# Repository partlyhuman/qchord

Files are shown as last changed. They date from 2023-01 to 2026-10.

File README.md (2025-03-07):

# Suzuki QChord Projects

Things that work with the Suzuki QChord, primarily a reproduction QCard that can be built with completely off-the-shelf parts. These projects are under active development.

# Physical devices

## [Q-Card Multicart QMC-001](pcbs/qcard-multicart)

You can get one as long as stock lasts <a href="https://ko-fi.com/s/ca15ec594a">at my Ko-Fi shop!</a>
<br>


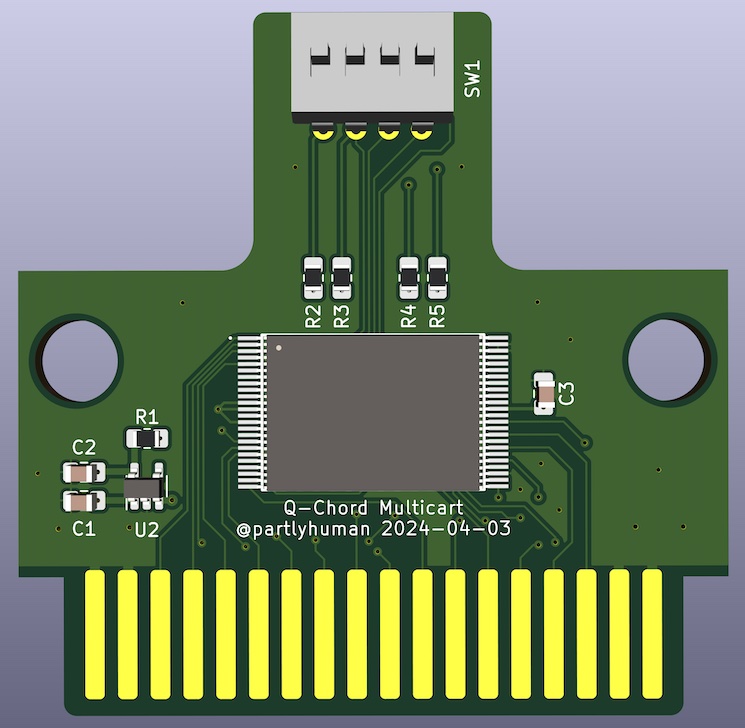
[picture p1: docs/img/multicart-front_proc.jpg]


A single cartridge that contains the entire Q-Card library, selectable by dip switches. The flash should be programmed prior to assembly, by concatenating the 4Mbit dumps you can find on archive.org.

## [Single Q-Card Reproduction](pcbs/qcard-single)

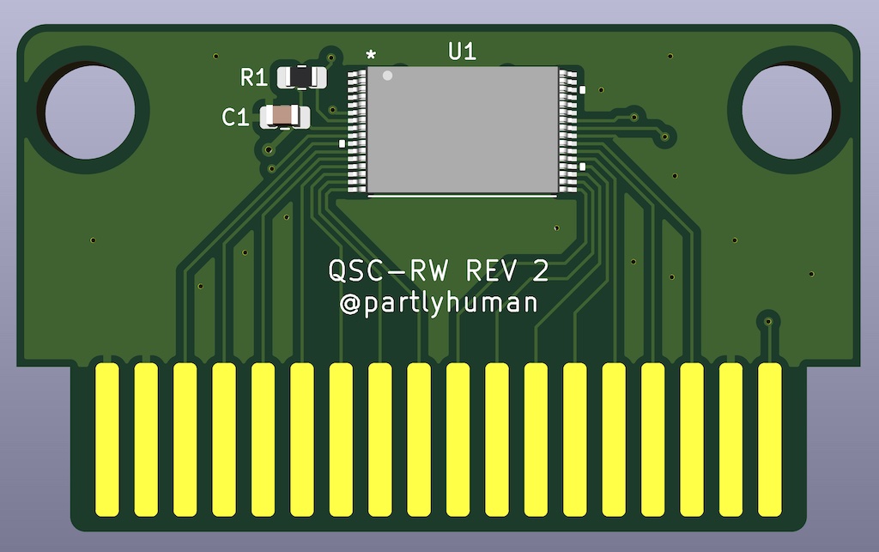
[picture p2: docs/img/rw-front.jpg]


A rewriteable reproduction QCard PCB using SMD components. The flash module uses a TSOP32 package. It can be reprogrammed after assembly with the programmer adapter below.

# [Documentation](docs/)

Including 

* my research notes on the Q-Card hardware & connector
* my reverse-engineered Q-Card format
* continuing research into the sound bank present on Q-Chord

# [Software](software/)

Primarily, the `qcard` command-line tool that can be used to convert MIDI to and from Q-Cards.

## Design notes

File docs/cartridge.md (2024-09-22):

# Hardware Notes

## Cartridge port

| description | bottom edge | top edge | description  |
| --- | --- | --- | --- |
| +5V | 1 | 2 | GND |
| A18 | 3 | 4 | GND |
| A17 | 5 | 6 | A16 |
| A14 | 7 | 8 | A15 |
| A13 | 9 | 10 | A12 |
| A8 | 11 | 12 | A7 |
| A9 | 13 | 14 | A6 |
| A11 | 15 | 16 | A5 |
| /OE | 17 | 18 | A4 |
| A10 | 19 | 20 | A3 |
| /CE | 21 | 22 | A2 |
| D7 | 23 | 24 | A1 |
| D6 | 25 | 26 | A0 |
| D5 | 27 | 28 | D0 |
| D4 | 29 | 30 | D1 |
| D3 | 31 | 32 | D2 |
| GND | 33 | 34 | GND/INSERTED |
| GND | 35 | 36 | NC |

### Notes
* QSC/QRD PCBs are labeled with pin 1 on the top. This uses the pin numbering found on the QC-1 mainboard and schematics, where pin 2 is on the top. 
* The schematic seems to indicate pins 1 and 2 are both VCC. This is not accurate and should be disregarded.
* INSERTED is connected to ground on QCards but read by the CPU to indicate cart presence.
* All data and control pins are limited with 100R on the QC-1 mainboard.

### Jumpers

Jumpers are used in some QCards to allow a single 4Mbit maskrom to be sold as two separate 2Mbit carts.

| jumper | connects | usage |
| --- | --- | --- |
| J401 | A18↔A18  | Address all of 4Mbit carts |
| J402 | A18↔VCC  | Only use high 2Mbit of 4Mbit cart |
| J403 | A18↔GND  | Only use low 2Mbit of 4Mbit cart  |

You can see these set in QSC2/3 which share a single 4Mbit rom.

### Cartridge revisions

Two major revisions exist, one with through-hole maskroms, one with SMD flash chips.
Newer 3.3V flash such as MX29LV800 is utilized on these revisions, and the 5V is dropped via a series of diodes.

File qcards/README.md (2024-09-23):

# Qcard documentation

Qcards contain MIDI data in a modified format. The following is an attempt to document them, as the product of reverse engineering work. There may be inaccuracies or omissions.

## Header

The header contains identifiers, some in preset fixed locations, and others (in variable length arrays) pointed to by these fixed locations. Data not in these special ranges is seemingly ignored, and there is no place for title, identifier, credits, etc.

| location | bytes | name | type | description |
| --- | ----  | --- | ---- | ---|
| `0005h` | 1 | CART_TYPE | `uint8_t` | which type of cart, `ROMPACK_SONG = 0x55` or `ROMPACK_RHYTHM = 0xAA` |
| `0010h` | 1 | LAST_TRACK | `uint8_t` | last track number (0-indexed), add one to get TRACKS, number of tracks |
| `0020h` | 2 | DATA_POINTER  | `*(void*)[TRACKS]` | 2-byte pointer to array of 3-byte pointers to beginning of each track |
| `0022h` | 2 | TEMPO_POINTER | `*uint8_t[TRACKS]` | 2-byte pointer to array of 1-byte tempos |
| `0024h` | 2 | LENGTH_POINTER| `*uint8_t[TRACKS]` | 2-byte pointer to array of 1-byte time signatures | 
| `*LENGTH_POINTER` | 1 * TRACKS | LENGTHS | `uint8_t[TRACKS]` | array of time signatures (the length of a measure in ticks, where a quarter note is subdivided into 48 ticks): `SAMBUN_LENGTH = 0x90` for ³⁄₄ time (3 * 48 = 144 = 0x90), or `SABUN_LENGTH = 0xC0` for ⁴⁄₄ time (4 * 48 = 192 = 0xC0). |
| `*TEMPO_POINTER`  | 1 * TRACKS | TEMPOS  | `uint8_t[TRACKS]` | array of 1-byte tempos, as a clock divider, so that higher values are faster. In MIDI, µs per quarter note = `20000 * (TEMPO + 10)` |
| `*DATA_POINTER` | 3 * TRACKS | DATAS | `(void*)[TRACKS]` | array of 3-byte pointers to the start of each track |

While the pointer locations are ordered `DATA_POINTER`, `TEMPO_POINTER`, `LENGTH_POINTER`, the locations they point to are typically laid out in the reverse order, contiguous: `LENGTHS`, `TEMPOS`, `DATAS`. As they are two-byte pointers, please ensure that all values in the array fall within the first 0x10000 bytes of the Qcard.

Note that 2- and 3-byte pointers are read out big-endian, e.g. `00 26` is 0x0026.

The magic number `0x55` which identifies a song Qcard is coincidentally the same value reserved for Suzuki in MIDI's manufacturer IDs.

## Data

Song data are stored as a stream of MIDI events with the following special treatments:

*Delta time*. in MIDI files, the delta time occupies a variable number of bytes (1-4, usually 1) before every event. In Qcards, events that occur at the same time omit the zero delta time. The next event that occurs after a positive delta time must indicate this by preceding the delta time with an `FF` byte and then the positive delta time. In other words, we encode sequences of 1 or more events that happen simultaneously, each sequence starting in the delta-time since the previous sequence, as follows: delta time, first event, zero or more events that happen at the same time (without timestamps), `FF`. If each event in a sequence has a positive delta time, yes, `FF` is used between each of them. The `FF` should not be interpreted as MIDI data.

`10 EVENT1 EVENT2 EVENT3 FF 20 EVENT4 FF 30 EVENT5 FF`

In this example, 10 ticks elapse, then events 1-3 occur simultaneously, then 20 ticks elapse, event 4 occurs, 30 ticks elapse and then event 5.

*Running status* is used extensively. If an event is followed by another event of the same status, the status byte is not repeated. This is used in standard MIDI as well. When an `FF` is encountered, this ends the running status as well as the running zero  timestamp.

*Implicit note-off velocity*. In note-off events, such as `99 2A 00`, the second byte is the note and the third byte is the velocity. Frequently, this velocity is 0. In Qcards, when velocity is zero, that byte is omitted, as in `99 2A`.

Keep in mind these rules all combine. Here, the three zero timestamps are omitted, all the zero note-off velocities are omitted, and the running status of `99` is continued throughout the run.

| MIDI | QCard |
| ---- | ----- |
| `01 99 2A 00` `00 99 66 00` `00 99 24 00` `00 99 71 00` | `01 99 2A 66 24 71 FF` |

The song data are essentially comprised of MIDI transformed by these special rules.

## Special events

System messages and system real-time messages, including sysex and meta events, are illegal: any status starting with `F?` should not be included in Qcards.

*Qcard end-of-track* is indicated by `FE`. Typically this is included a number of times at the end of a track after a run end, such as `FF FE FE FE FE FE`.

*Metronome* flashing is triggered by a special event `B0 2C 7F`, nominally a controller change on channel 1, "effect control 1", value `01111111`.

*Chords* are encoded in MIDI as `AA` events, nominally polyphonic key pressure on channel 11. See below for chord bytes.

## Channels

Quite a few channels are reserved by the Qchord for various purposes. Therefore, these channels should be avoided when authoring Qcards, although it's possible you can stretch this.

Additionally, the channels are pre-assigned to be muted and activated by the "Auto Chord" and "Chord Plus" buttons.

| Channel | QCard  | Use | Notes |
| --- | --- | --- | ----- |
| 1  | | MELODY KEYBOARD | Reserved for user playing on melody keyboard (piano mode). Metronome inserted on this channel (not audible).
| 2  | | ??? | 
| 3  | ☑️ | CHORD PLUS | Song data, muted by "Chord Plus" button. Should be the main melody.
| 4  | | ???
| 5  | ☑️ | AUTO CHORD 1 | Song data, muted by "Auto Chord" button. Should be accompaniment.
| 6  | ☑️ | AUTO CHORD 2 | Song data, muted by "Auto Chord" button. Should be accompaniment.
| 7  | ☑️ | AUTO CHORD 3 | Song data, muted by "Auto Chord" button. Should be accompaniment.
| 8  | ☑️ | AUTO CHORD 4 | Song data, muted by "Auto Chord" button. Should be accompaniment.
| 9  | ☑️ | BASS | Song data. Should be bassline.
| 10 | ☑️ | DRUMS | Song data. Drums should be on this channel.
| 11 | 🆗 | CHORD DATA | Reserved for chord data.
| 12 | 🆗 | EXTRA | Extra channels for song data.
| 13 | 🆗 | EXTRA | Extra channels for song data.
| 14 | | STRUMPLATE | Reserved for user playing on strum bar.
| 15 | | STRUMPLATE | Reserved for user playing on strum bar.
| 16 | | STRUMPLATE | Reserved for user playing on strum bar.

SAFE MODE: Channels 3 + 5-10 can be considered "safe mode." All Qcard songs use them and they have a single assigned purpose. (7 channels)

Extended mode: Channels 12-13 are also used in some QCards, so using them is fine too. Some songs use notes on channel 11. This brings the extended total to 10 channels.

Generally one channel is used per instrument, but some Qcard songs do program changes!

## Tempo

The MIDI messages for tempo and time signature are not used by QCards, instead they are set in the header arrays. See above for some notes on conversion.

QChord uses a preset 48 parts per quarter note subdivision.

## Chords

The chords that you can play along with are encoded in the song data as `AA` key pressure events on channel 11. In Qcards, the first byte is always `AA`, the second byte represents the chord, and the third byte is `00`. The chord byte can be further split into two nibbles:

The *Chord quality* is represented by the upper digit 1-7. It's easiest to visualize these as the result of holding down the chord buttons. There are three rows of buttons on the Qchord, represented by the three bits. The top row, major chords, is the least significant bit `1`; the middle row, minor chords, the second bit `10`; the bottom row, 7th chords, is the most significant bit `100`:

| nibble | 7th | Min | Maj | Result |
|---|---|---|---|---|
| **1** | 0 | 0 | 1 | Major |
| **2** | 0 | 1 | 0 | Minor |
| **3** | 0 | 1 | 1 | Diminished |
| **4** | 1 | 0 | 0 | 7th |
| **5** | 1 | 0 | 1 | Major 7th |
| **6** | 1 | 1 | 0 | Minor 7th |
| **7** | 1 | 1 | 1 | Augmented |

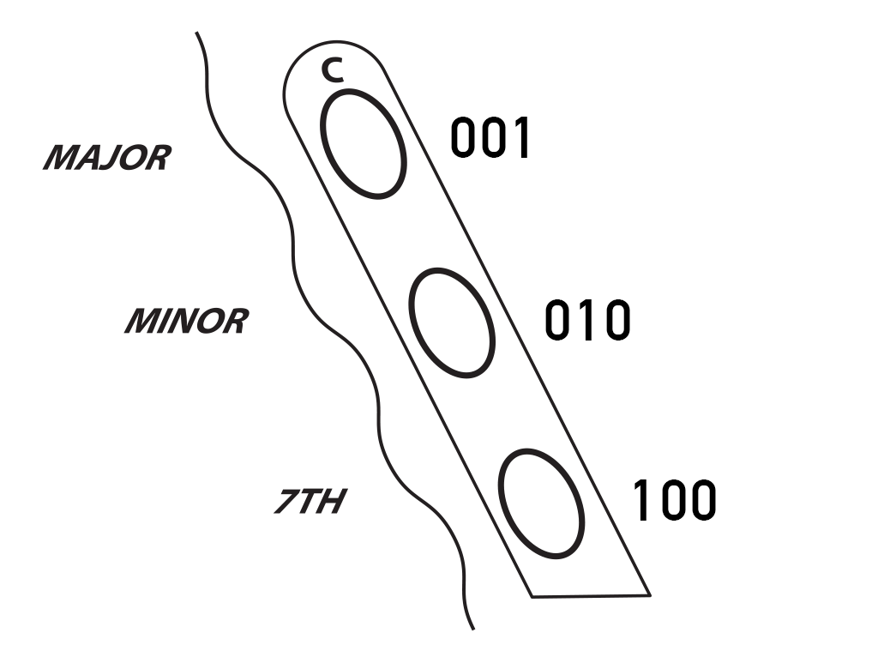
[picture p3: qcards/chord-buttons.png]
Qcard Chord buttons


The *Root note* is represented by the lower digit 0-B.

| **nibble** | 0 | 1 | 2 | 3 | 4 | 5 | 6 | 7 | 8 | 9 | A | B |
|---|---|---|---|---|---|---|---|---|---|---|---|---|
| **note** | C | D♭| D | E♭| E | F | F♯| G | A♭| A | B♭| B |

Therefore, the byte `10` is CMaj, the byte `29` is Amin, etc. Again, the full events would be `AA 10 00` and `AA 29 00`.

## Lead in and out

Some common initialization sequences found at the beginning of all QChord-flavoured MIDI:

* Control Change / program channels / 121 Reset all controllers / 0
* Control Change / program channels / 7 Volume / [0-127]
* Control Change / program channels / 10 Pan / [0-127, 64=center]
* Control Change / program channels / 91 Reverb Send Level / [0-127]
* Control Change / program channels / 93 Chorus Send Level / [0-127]
* Control Change / program channels / 1 Modulation / 0
* Control Change / program channels / 64 Hold 1 / 0
* Pitch Bend / program channels / 0
* Program Change / program channels / [Set up instruments]
* Program Change / drums 10 / 0 Piano 1 [? curious, maybe drums override this]
* Program Change / chords 11 / [65, 51... does this set strum instrument?]

Not everything takes place at 00:00, these are spread out along the first second. The ordering changes but 121 reset all comes first. Pan is used, supporting stereo, just not on the built-in mono speaker.

Nothing special seems to happen at the end of tracks.

## Reference implementation

You can use the `qcard2midi` and `midi2qcard` software as reference implementations. See the source [here](https://github.com/partlyhuman/qchord/tree/master/qcard-tools/MidiQcard/Partlyhuman.Qchord.Common).

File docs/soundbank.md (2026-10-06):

# Soundbank Notes

## Quick Ref

* Controller: SAM9713
* Soundbank ROM PART: GMS960800B
* Based on soundbank SET: GSSBK080

## Default instruments

| preset | #  | GM instrument name |
| --- | -  | --- |
| Guitar | 26 | ELECTRIC GUITAR(JAZZ) |
| Piano | 0  | ACOUSTIC GRAND PIANO |
| Strings | 48 | STRINGS ENSEMBLE 1 |
| Vibes | 11 | VIBRAPHONE |
| Organ | 19 | CHURCH ORGAN |
| Voice | 53 | VOICE OOOHS |
| Flute | 75 | PAN FLUTE |
| Harp | 46 | ORCHESTRAL HARP |
| Synths | 82 | LEAD 3(CALLIOPE) |
| SFX | 98 | Drum kit |

Appears as array in Program ROM @10A9h

```1A 00 30 0B 13 35 4B 2E 52 62```

## Creating a SAM9713 ROM from a 94B Soundbank

> This is now possible for GSSBK040, GSSBK080! See [video of the first successful test](https://www.youtube.com/watch?v=fGnvm3H4Y6E) where I created a ROM for SAM9713 injected with the GMBK9708 Dream/Roland sound set.

A ROM for SAM chips combine firmware for the target chip and a specially compiled and relocated 94B sound font. Using the SAM tools we can now make working ROMs for the SAM9713 / Q-Chord.

The 94B sound bank must fit in 1MB, and should be a complete General MIDI set (including instruments 0-99).

1. Obtain the `97PNP2_V50` cd image from https://archive.org/details/97-pnp-2-v-50
2. Mount the image and install the DREAM Editors from `SNDEDIT/SETUPED.EXE`. This can be done in a Windows 95-2000 VM, but should also still run in Windows 10!
3. Run the DREAM Bank Editor (`94WBANK.EXE`) and ignore the hardware not found error
4. Make a working directory like `C:\TEMP`
5. Use Sound Bank > New > Empty Sound Bank to create a new sound bank and save it to the working directory, like `C:\TEMP\TEMP.94K`
6. Copy your 94B sound bank and name it after your project e.g. `C:\TEMP\TEMP.94B`. As long as you don't compile the new soundbank, the tool assumes that this is the output of compiling your sound bank and you can perform these steps without having a source `94K`
7. Use Tran[s]fer > Binary File to start preparing a ROM
8. Use a Start Address of `0x3400` and a Memory Size of `0x80000` and hit OK. The addresses are in *16-bit words*, so this refers to byte `0x6800` in the 1MB ROM. This relocates all the addresses of the instrument parameters, and sets things up to place the sound bank data in the same position as it was in the GMS960800B ROM.
9. Now, combine the firmware from 0h—6800h of the GMS960800B dump, and the sound bank generated in `C:\TEMP\TEMP.BIN`. You can use `dd`, or even more basic with `cat`:

```
cp GMS960800B.bin firmware.bin
truncate firmware.bin --size 26624
cat firmware.bin TEMP.BIN > newrom.bin
```

## Creating a SAM9713 ROM from any sound font

I've been able to use a combination of tools, with some commonalities to the "SF2 to 94B" process below.

* SF2 -> DLS: Awave Studio
  * !! Compiling the 94L->94K will fail down the line if you don't ensure that the wave samples are saved out with DOS 8.3 compatible names, so spend some time renaming samples to be 8 alphanumeric chars only
  * Export as DLS *Level 1*
* DLS -> 94I, 94L: DLSREAD.EXE
* 94L -> 94K: Guillemot ISIS Soundbank Manager MemManager.EXE
  * This was the biggest challenge, finding software that will compile a .94L to a .94K!
  * I managed to run this without hardware by adding specific registry keys, and patching the driver DLL. Tools in /soundfont/tools/.
  * Ensure you install the registry keys by opening `MemManager Registry Keys.reg`. You may also then want to run Regedit and update the install path in `HKEY_LOCAL_MACHINE\SOFTWARE\WOW6432Node\Guillemot\Maxi Studio ISIS\Memory Manager\General\Application Path`.
  * If you run into errors with not found WAVs here, most likely the WAV does not have a valid DOS 8.3 name, remember these are old old tools.
* 94K -> 94B: MemManager.EXE
* 94B -> BIN: 94WBANK.EXE from the 97PNP2 tools CD
  * Use the steps above, except if you did this process you have a valid .94K so you don't have to fool it, you can open it instead of creating a new file

Unfortunately all NON-DREAM soundfonts I've tried thus far will actually play the correct instrument but panic and hang during the first note (possibly at the first loop point?). But....

## Closing the gap and adding Omnichord sound to the Q-Chord

Hanging is due to envelope settings that exist in DLS level 1 but not in the 94* specifications. Fixing this up in the .94b is possible with a script.

Finally, injecting instruments from one .94b into another .94b is done with a script. Primarily this has to relocate pointers in the RELOC chunk. The 94b format is documented albeit complex, RIFF-based, and fairly easily parsed.

An Omnichord instrument was created in Awave Studio from the [Chordian](https://github.com/Jan125/sfz.chordian) single-note sample data; not using the .sfz itself as that replicates chording, backing, etc. in the instrument. We create that as program 26, the elec. guitar that's the Q-Chord's default. Then we follow above steps to convert DLS->94L->94K->94B. Use scripts to fixup the envelopes and replace program 26 in the original `GSSBK080.94b`. Then continue steps above to convert 94B->BIN, re-assemble with the original firmware, and burn.

## Findings

Dump of ROM contains the ASCII text

> GMS960800B  V1.0 October 1997 COPYRIGHT DREAM SA 1993-1997

This shows up in the datasheet for the Atmel SAM9713, an all-in-one MIDI control which is present in Q-Chord as Q615.

> Available firmware/sample set for turnkey designs
>
> — 8 Mbit GS GMS960800B (**)
> 
> — 8 Mbit CleanWave® GMS970800B

So this was basically an all-in-one solution from Dream/Atmel. Also found in the binary is the ASCII `GSSBK080` which is the name of the source sound font used in the chipset (confirmed).

## SAM9713

[Datasheet](https://www.dosdays.co.uk/media/dream/SAM9713.PDF)

Docs for SAM9407, should be similar? *Note at least pinout differs, SAM9409 is TQFP144, SAM9713 is TQFP80*

[Programmer reference](sam9407-docs/SAM9407%20Programmer%20Reference.pdf) ⭐

[Datasheet](sam9407-docs/SAM9407_datasheet.pdf)

[Specs](sam9407-docs/SAM9407_specs.pdf)

Note UART MIDI mode, pretty sure this is connected to the QChord midi ports.

One interesting possibility is that it seems to support digital audio, unused by the Q-chord...

## About the manufacturers

Dream, Makers of CleanWave sound banks and probably distributor of SAM9713. I think Atmel purchased them at some point. Roland produced the sound banks and Dream stole, then licensed, them.

https://dream.fr/other-documents.html

https://dosdays.co.uk/topics/wavetable_audio.php

## PC Sound cards with SAM9713 chipset

The SAM9713 or its cousin the SAM9407 is found in at least two sound cards from the 1990s:

[Guillemot Maxi Sound 64 Home Studio](https://retronn.de/imports/hs64_config_guide.html) comes with some DOS software?

https://retronn.de/imports/hwgal/hw_maxi_sound_64_home_studio.html

[EW64](https://www.vogonswiki.com/index.php/EWS64)

https://retronn.de/imports/hwgal/hw_ews64xl_front.html

This has a bunch of 98b files

Great references:

* https://retronn.de/imports/hwgal/hwgal_empty.html and their FTP
* http://dosdays.co.uk/topics/wavetable_audio.php
* https://waveblaster.nl/

http://www.vogonsdrivers.com/getfile.php?fileid=144
> DMF format as used by Hoontech is identical to 94B, just rename file.
TTS format that is sometimes used by Terratec adds a header to the 94B file, but there is a TTS 94B converter available on the Terratec ftp.

> Dream released 4 new sound synthesis/processing ICs in March 1998. They were the SAM9707, SAM9703, SAM9713 and SAM9733. The SAM9707 was a marketed as a direct replacement for the SAM9407 on high-end PC sound cards and the SAM9703 was to replace the SAM9503 on high-end karoake systems. The SAM9713 was marketed for use in karaoke systems, and the SAM9733 for low-cost keyboards.

> The CleanWave 32(TM) is possibly a Roland patchset used without permission. Roland took Dream to court over the use of their samples/patches and won. On 2nd October 1997, Dream and Crystal Semiconductor acknowledged Roland's copyright in its digital sound recordings. Roland then authorised Dream (and its parent company, Atmel) to resell ICs with Roland GS recordings on. CleanWave 32 came with 128 GM instruments plus 195 variations, 9 drumsets and 1 sound effects set.

> Dream also produced a CleanWave 8 (1 MB ROM), CleanWave 16 (2 MB ROM), and CleanWave 64 (8 MB ROM).

## Software

The widest array of software seems to be that bundled with the drivers for the sound cards mentioned above. The TerraTec FTP site has outstanding archives of these, though they need to be run in DOS and/or Windows 98/2000: ftp://retronn.de/driver/TerraTec/EWS/ ftp://retronn.de/driver/Guillemot/MaxiSound64HomeStudio/

Others:

https://www.fmjsoft.com/awavestudio.html#main

http://www.studio4all.de/htmle/welcomeewst.html

http://web.archive.org/web/20080314220936/ftp://www.ews64.com/download/vsampler17b1.zip

Tools and even gerbers for reference design for SAM9407 sound card 
https://archive.org/download/97-pnp-2-v-50
https://archive.org/details/manualzilla-id-5727655
found at
https://www.vogons.org/viewtopic.php?t=92271

## CleanWave8

The other ROM is GMS970800, now dumped. Seems to correlate to GMBK9708.94B. `GMBK9708` appears at 0x10180.

Unfortunately, it is not a drop-in replacement, likely because as we now know, the dump contains firmware+soundbank, and the GMS970800 dumped was for use with SAM9503. The correct part for SAM9713 is probably GMS970800*B*.

# Conversions

## DLS to 94B

These appear to be most closely related

[MinimalMIDIPlayer](https://github.com/SamusAranX/MinimalMIDIPlayer)  can use DLS sound fonts as can 
[Timidity++](https://en.wikipedia.org/wiki/TiMidity%2B%2B)

https://retronn.de/imports/dream_tricks.html

> Is it possible to easily convert soundfonts to 94B format?

> In a way yes. The Maxi Sound 64 Utilities allow to load DLS sound fonts directly. Internally the Utilities convert the DLS sound font on the fly to a 94B file. The program asks if you want to save the generated 94B elsewhere. It loads the 94B and deletes the temporary generated file. In combination with the previously described bug in the Win9x driver the 94B is already deleted when the Utilties ask to save it when the load fails. The only way is to copy the generated 94B manually from the TEMP folder while the error message is displayed. In NT4 however everything works fine.
There are tools to convert the common SBK, SF2 fonts to DLS first. It is unclear if specific information gets lost on conversion. It appears however that the resulting 94B sound fonts are good.
To convert SF2 to DLS the Extreme Sample Converter 3.6.0 Demo can be used. Choose as Source Format SF2 and as Destination Format DLS/Bank, press convert.

## SF2 to 94B

Documenting what happens in [this video](https://www.youtube.com/watch?v=MRmAzK0iHUY):

> I have not found a program to convert .sf2 files to .94b directly
> 
> I convert .sf2 files to .dls using Awave Studio
> 
> Then, use dlsread.exe to convert .dls to .wav, .94i, .94l
> 
> Finally: Guillemot Soundbank Manager, import .94l list to .94k and compile to .94b
> 
> Converting .sf2 to .dls in Awave Studio
> 
> 1. Delete unused & duplicate waveforms
> 2. Replace special characters like `(.;~"` from wave names
> 3. Same for instrument names
> 4. Save as DLS level 1 spec
> 5. Sometimes, do not save all regions (message)
> 
> How to convert DLS to Sound Bank (.94b)
> 
> 1. Run dlsread.exe
> 2. File > Open, choose DLS file
> 3. Press "Extract Bank" and you can get .wav, .94i, .94l
> 4. Run 94ubank(?)
> 5. Sound Banks > New
> 6. Choose .94l from #3
> 7. Press OK, .94k will be made
> 8. Sound Banks > Open, choose .94k
> 9. Press COMPILE, .94b will be made
> 
> DLS site: http://www.microsoft.com/music/setup.htm
> 

## 94B to Anything

https://www.vogons.org/viewtopic.php?t=58271

https://www.vogons.org/viewtopic.php?f=62&t=56535

## Using Flash in its place

Verified copying to a MX29F800 works, with a small tweak:

Ensure pins 43/WE# and 44/RESET# are pulled HIGH. These are NC in the PCB so jumper them to 33/BYTE.

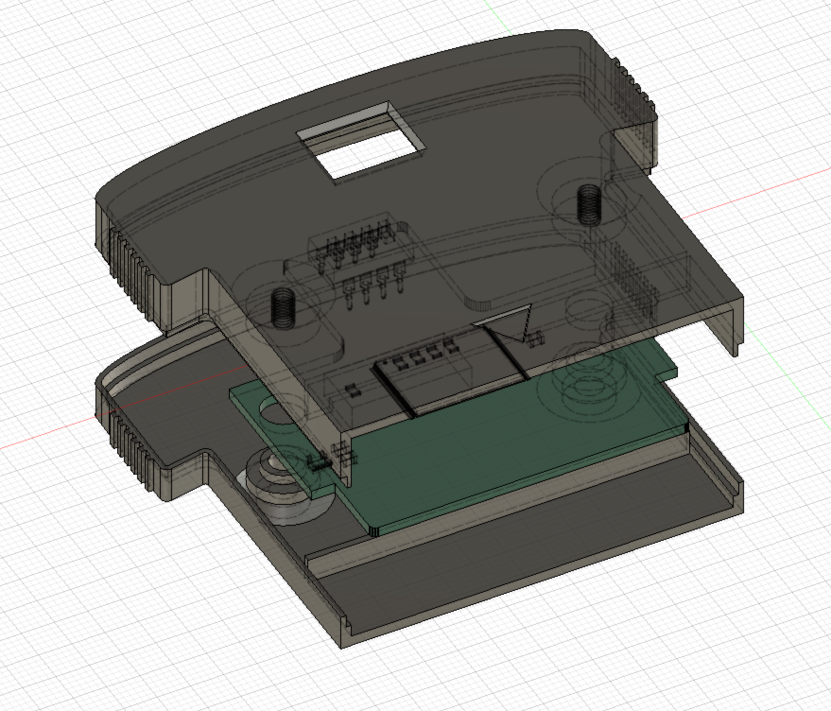
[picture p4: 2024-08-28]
docs/img/screenshot-case.png

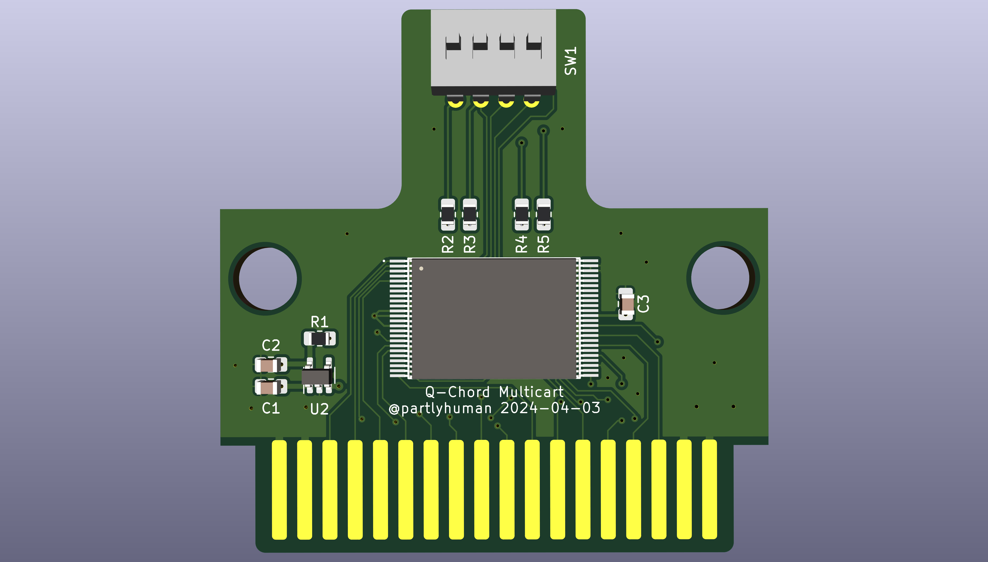
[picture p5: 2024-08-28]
docs/img/multicart-front.png

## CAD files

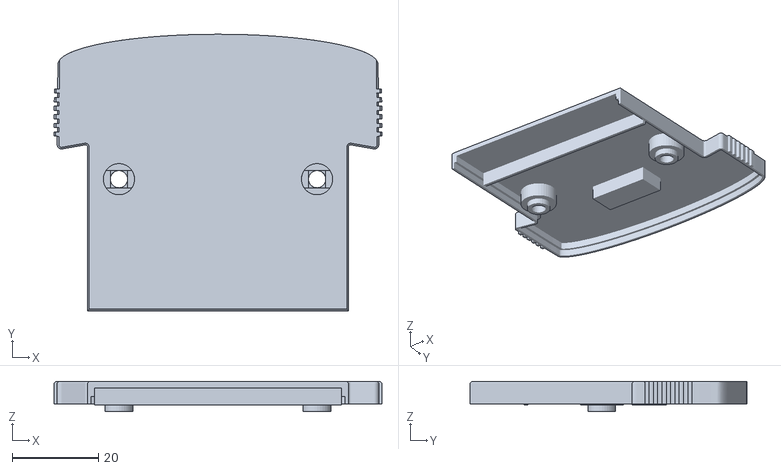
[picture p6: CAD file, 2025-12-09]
prints/Q Card Case_Q Card Multicart Case v21_Bottom.stl
76.1 x 64.2 x 7.05

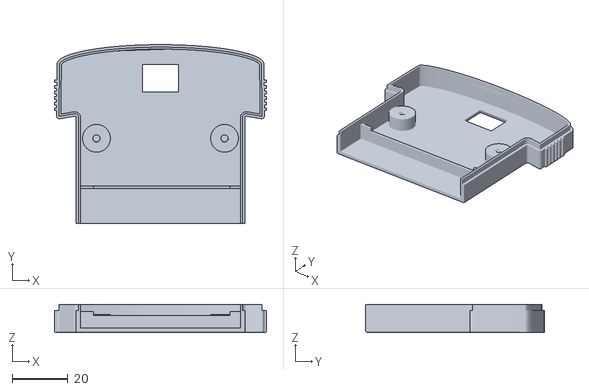
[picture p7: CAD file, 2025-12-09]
prints/Q Card Case_Q Card Multicart Case v21_Top.stl
76.1 x 64.2 x 10.2

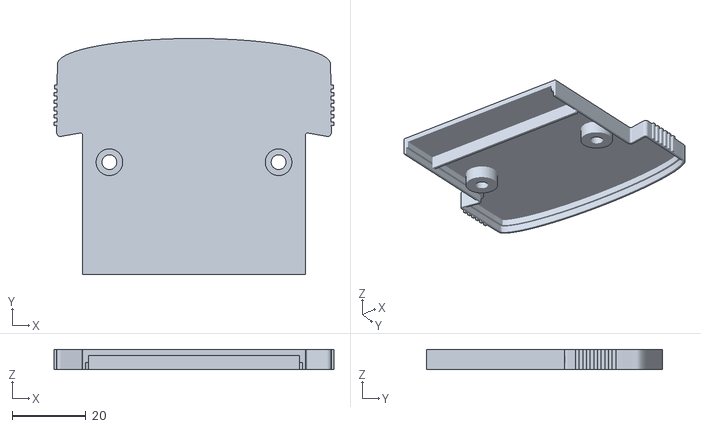
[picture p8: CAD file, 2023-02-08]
prints/Q Card Case_Bottom.stl
76.1 x 64.2 x 5.50

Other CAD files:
prints/Q Card Case_Top.stl

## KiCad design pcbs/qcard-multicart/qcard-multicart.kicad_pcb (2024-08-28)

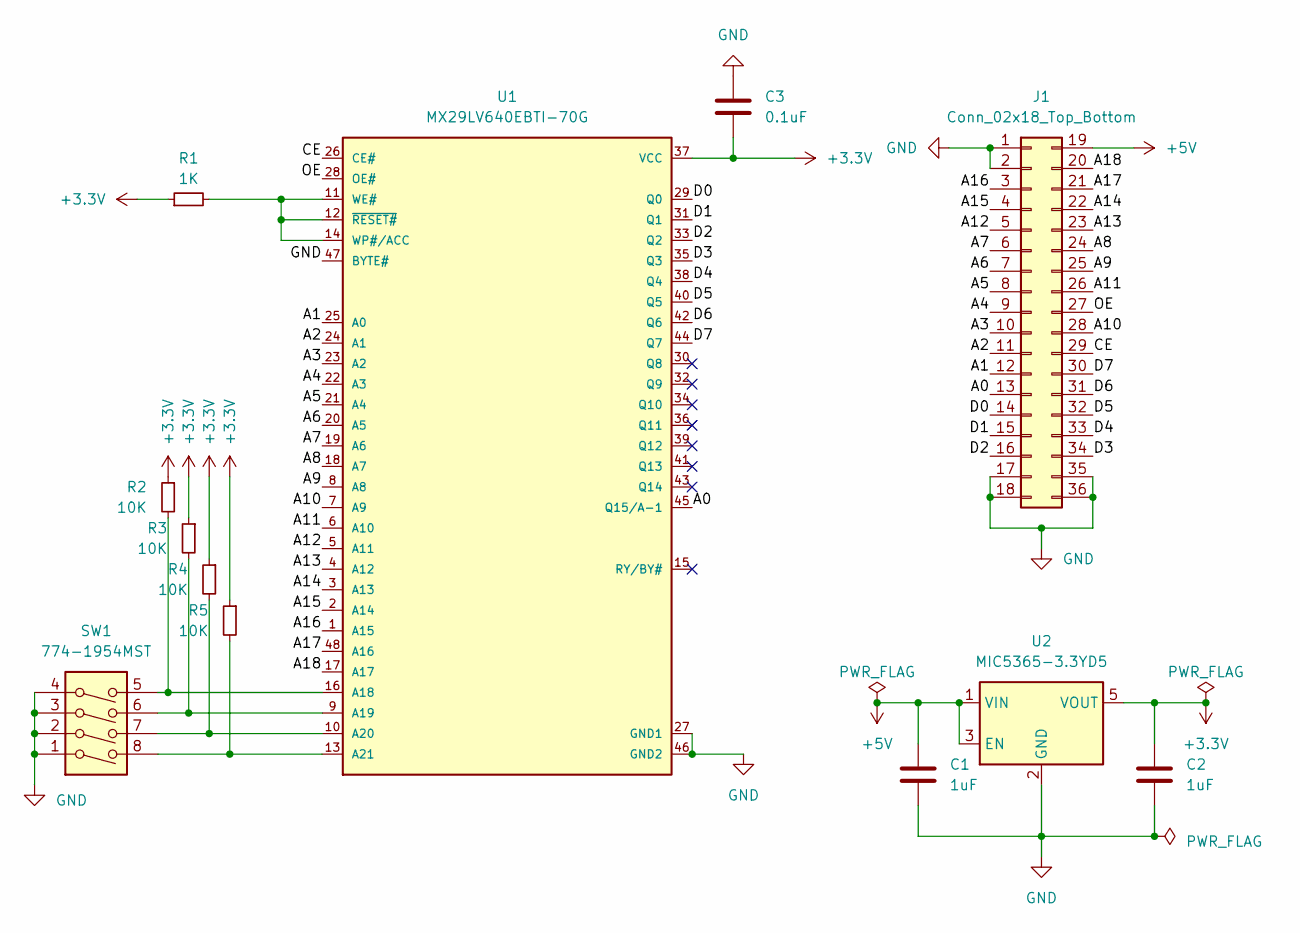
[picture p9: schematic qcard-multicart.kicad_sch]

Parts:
C1, C2: 1uF; C_0805_2012Metric_Pad1.18x1.45mm_HandSolder
C3: 0.1uF; C_0805_2012Metric_Pad1.18x1.45mm_HandSolder
J1: Conn_02x18_Top_Bottom; REB_EdgeConnector_36pin
R1: 1K; R_0805_2012Metric_Pad1.20x1.40mm_HandSolder
R2, R3, R4, R5: 10K; R_0805_2012Metric_Pad1.20x1.40mm_HandSolder
SW1: 774-1954MST; DIP-8_W7.62mm
U1: MX29LV640EBTI-70G; SOP50P2000X120-48N
U2: MIC5365-3.3YD5; SOT-23-5

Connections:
+3.3V: C2.1, C3.2, R1.1, R2.1, R3.1, R4.1, R5.1, U1.37 (VCC), U2.5 (VOUT)
+5V: C1.1, J1.19, U2.1 (VIN), U2.3 (EN)
/A0: J1.13, U1.45 (Q15/A-1)
/A1: J1.12, U1.25 (A0)
/A2: J1.11, U1.24 (A1)
/A3: J1.10, U1.23 (A2)
/A4: J1.9, U1.22 (A3)
/A5: J1.8, U1.21 (A4)
/A6: J1.7, U1.20 (A5)
/A7: J1.6, U1.19 (A6)
/A8: J1.24, U1.18 (A7)
/A9: J1.25, U1.8 (A8)
/A10: J1.28, U1.7 (A9)
/A11: J1.26, U1.6 (A10)
/A12: J1.5, U1.5 (A11)
/A13: J1.23, U1.4 (A12)
/A14: J1.22, U1.3 (A13)
/A15: J1.4, U1.2 (A14)
/A16: J1.3, U1.1 (A15)
/A17: J1.21, U1.48 (A16)
/A18: J1.20, U1.17 (A17)
/CE: J1.29, U1.26 (CE#)
/D0: J1.14, U1.29 (Q0)
/D1: J1.15, U1.31 (Q1)
/D2: J1.16, U1.33 (Q2)
/D3: J1.34, U1.35 (Q3)
/D4: J1.33, U1.38 (Q4)
/D5: J1.32, U1.40 (Q5)
/D6: J1.31, U1.42 (Q6)
/D7: J1.30, U1.44 (Q7)
/OE: J1.27, U1.28 (OE#)
GND: C1.2, C2.2, C3.1, J1.1, J1.2, J1.17, J1.18, J1.35, J1.36, SW1.1, SW1.2, SW1.3, SW1.4, U1.27 (GND1), U1.46 (GND2), U1.47 (BYTE#), U2.2 (GND)
unnamed: R2.2, SW1.5, U1.16 (A18)
unnamed: R3.2, SW1.6, U1.9 (A19)
unnamed: R4.2, SW1.7, U1.10 (A20)
unnamed: R5.2, SW1.8, U1.13 (A21)
unnamed: R1.2, U1.11 (WE#), U1.12 (~RESET#), U1.14 (WP#/ACC)

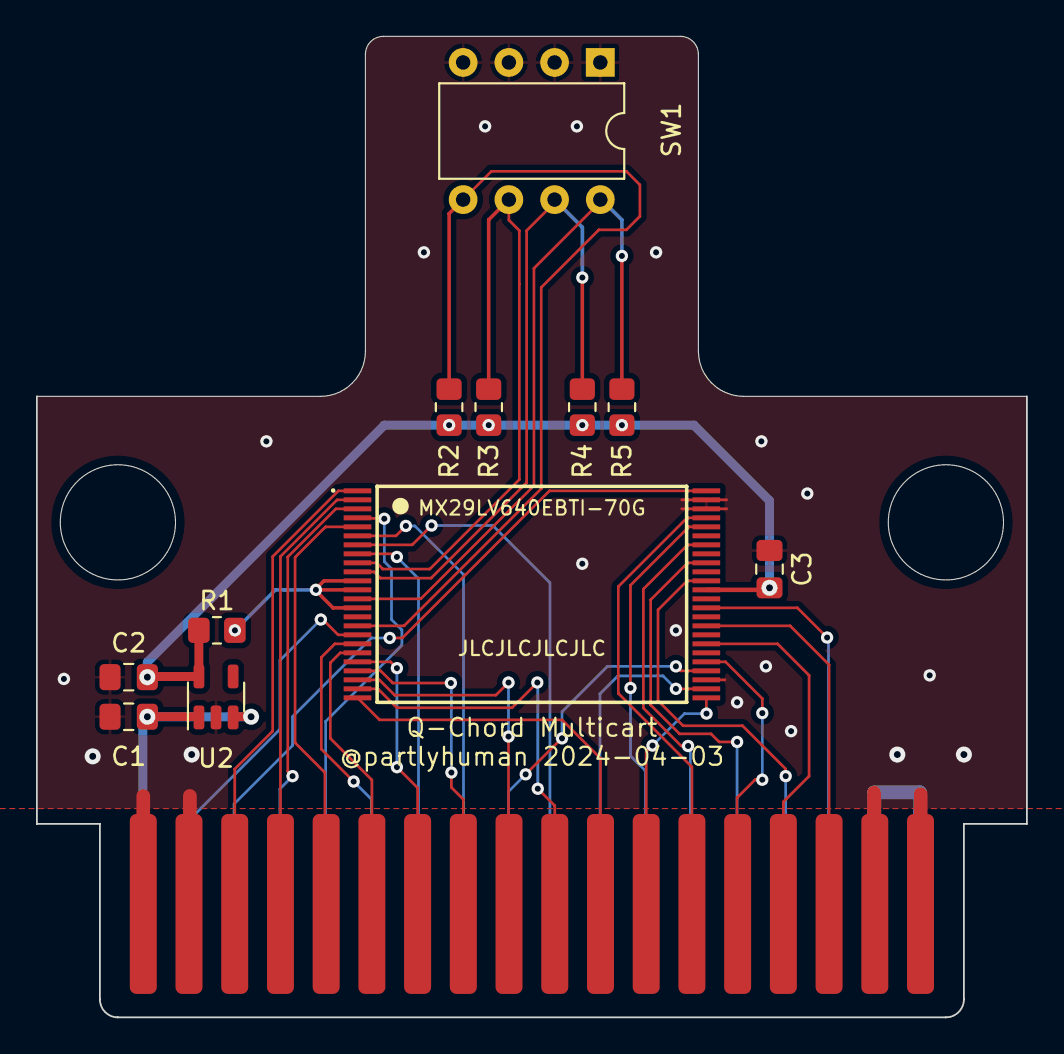
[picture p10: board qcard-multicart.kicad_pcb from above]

Board: 2 copper layers, 55.0 x 54.5 mm, 14 parts (0 on the bottom side), 37 nets.

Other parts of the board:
H1, H2: MountingHole_6.4mm_M6

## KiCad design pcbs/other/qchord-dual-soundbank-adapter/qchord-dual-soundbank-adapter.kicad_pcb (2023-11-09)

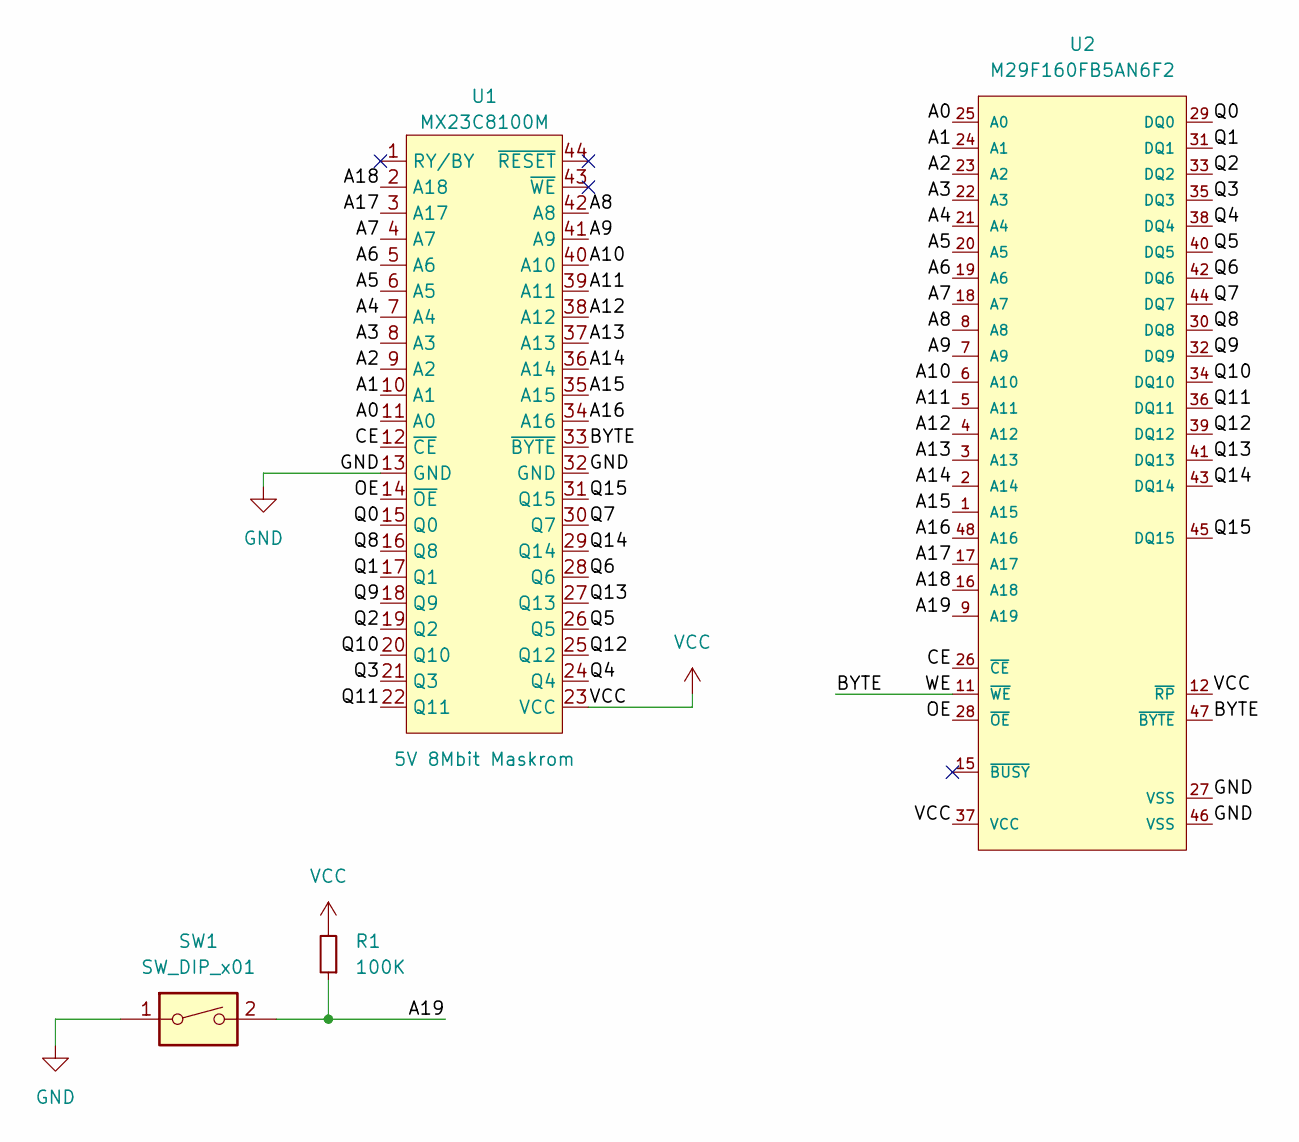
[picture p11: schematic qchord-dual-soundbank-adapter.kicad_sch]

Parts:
R1: 100K; R_0805_2012Metric_Pad1.20x1.40mm_HandSolder
SW1: SW_DIP_x01; SW_DIP_SPSTx01_Slide_9.78x4.72mm_W8.61mm_P2.54mm
U1: MX23C8100M; PSOP-44_Castellated
U2: M29F160FB5AN6F2; Micron-M29F160FB5AN6F2-Manufacturer_Recommended; Voltage 4.5V-5.5VÂ; Part Family M29FÂ

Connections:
/A0: U1.11 (A0), U2.25 (A0)
/A1: U1.10 (A1), U2.24 (A1)
/A2: U1.9 (A2), U2.23 (A2)
/A3: U1.8 (A3), U2.22 (A3)
/A4: U1.7 (A4), U2.21 (A4)
/A5: U1.6 (A5), U2.20 (A5)
/A6: U1.5 (A6), U2.19 (A6)
/A7: U1.4 (A7), U2.18 (A7)
/A8: U1.42 (A8), U2.8 (A8)
/A9: U1.41 (A9), U2.7 (A9)
/A10: U1.40 (A10), U2.6 (A10)
/A11: U1.39 (A11), U2.5 (A11)
/A12: U1.38 (A12), U2.4 (A12)
/A13: U1.37 (A13), U2.3 (A13)
/A14: U1.36 (A14), U2.2 (A14)
/A15: U1.35 (A15), U2.1 (A15)
/A16: U1.34 (A16), U2.48 (A16)
/A17: U1.3 (A17), U2.17 (A17)
/A18: U1.2 (A18), U2.16 (A18)
/A19: R1.1, SW1.2, U2.9 (A19)
/BYTE: U1.33 (~BYTE), U2.11 (~WE), U2.47 (~BYTE)
/CE: U1.12 (~CE), U2.26 (~CE)
/OE: U1.14 (~OE), U2.28 (~OE)
/Q0: U1.15 (Q0), U2.29 (DQ0)
/Q1: U1.17 (Q1), U2.31 (DQ1)
/Q2: U1.19 (Q2), U2.33 (DQ2)
/Q3: U1.21 (Q3), U2.35 (DQ3)
/Q4: U1.24 (Q4), U2.38 (DQ4)
/Q5: U1.26 (Q5), U2.40 (DQ5)
/Q6: U1.28 (Q6), U2.42 (DQ6)
/Q7: U1.30 (Q7), U2.44 (DQ7)
/Q8: U1.16 (Q8), U2.30 (DQ8)
/Q9: U1.18 (Q9), U2.32 (DQ9)
/Q10: U1.20 (Q10), U2.34 (DQ10)
/Q11: U1.22 (Q11), U2.36 (DQ11)
/Q12: U1.25 (Q12), U2.39 (DQ12)
/Q13: U1.27 (Q13), U2.41 (DQ13)
/Q14: U1.29 (Q14), U2.43 (DQ14)
/Q15: U1.31 (Q15), U2.45 (DQ15)
GND: SW1.1, U1.13 (GND), U1.32 (GND), U2.27 (VSS), U2.46 (VSS)
VCC: R1.2, U1.23 (VCC), U2.12 (~RP), U2.37 (VCC)

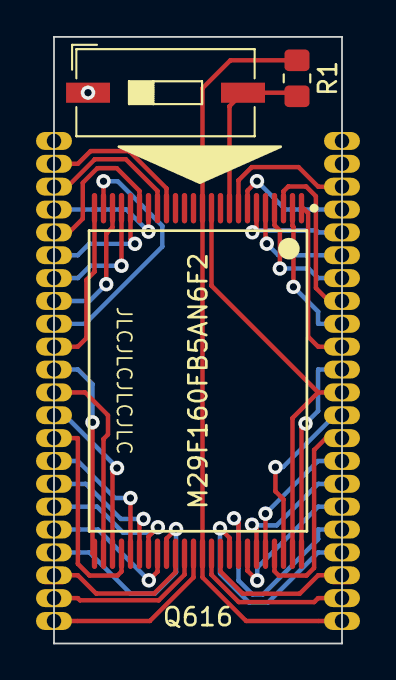
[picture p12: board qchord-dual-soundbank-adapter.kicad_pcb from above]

Board: 2 copper layers, 16.0 x 33.7 mm, 4 parts (0 on the bottom side), 41 nets.

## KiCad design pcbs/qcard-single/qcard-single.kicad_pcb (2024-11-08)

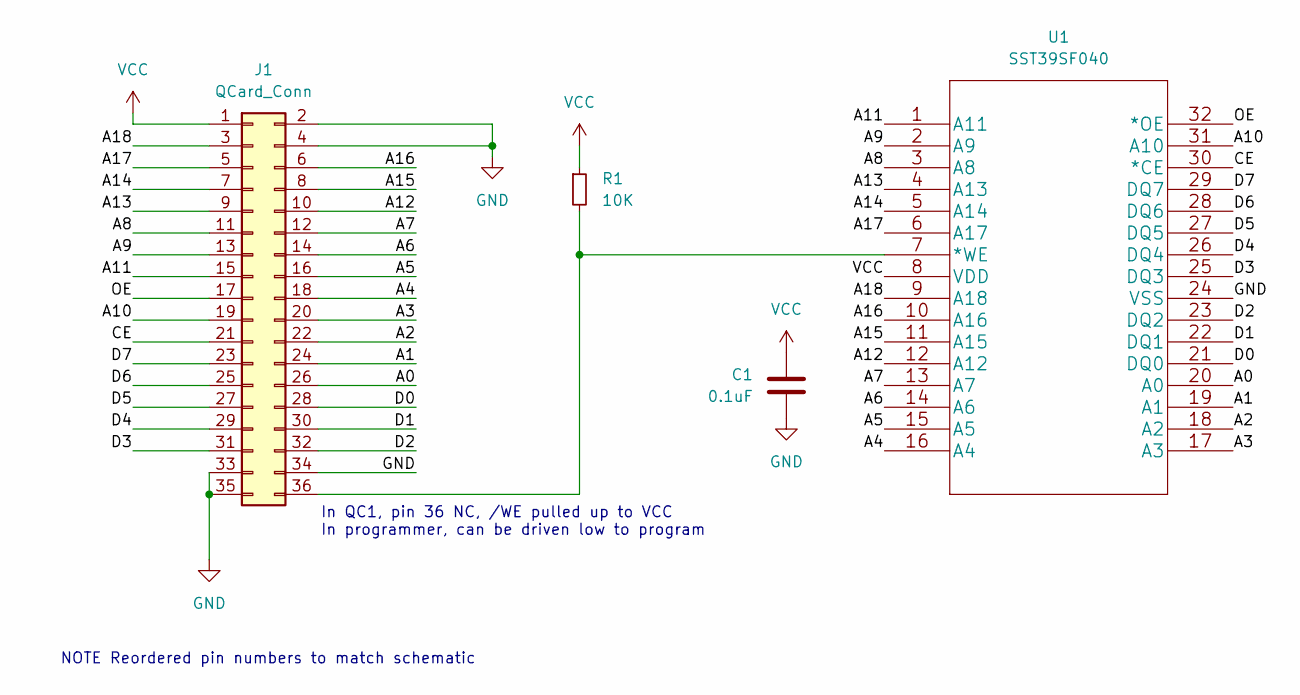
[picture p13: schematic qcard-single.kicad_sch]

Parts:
C1: 0.1uF; C_0805_2012Metric_Pad1.18x1.45mm_HandSolder
J1: QCard_Conn; REB_EdgeConnector_36pin
R1: 10K; R_0805_2012Metric_Pad1.20x1.40mm_HandSolder
U1: SST39SF040; SST39SF040-55-4C-WHE-T

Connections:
/A0: J1.26, U1.20 (A0)
/A1: J1.24, U1.19 (A1)
/A2: J1.22, U1.18 (A2)
/A3: J1.20, U1.17 (A3)
/A4: J1.18, U1.16 (A4)
/A5: J1.16, U1.15 (A5)
/A6: J1.14, U1.14 (A6)
/A7: J1.12, U1.13 (A7)
/A8: J1.11, U1.3 (A8)
/A9: J1.13, U1.2 (A9)
/A10: J1.19, U1.31 (A10)
/A11: J1.15, U1.1 (A11)
/A12: J1.10, U1.12 (A12)
/A13: J1.9, U1.4 (A13)
/A14: J1.7, U1.5 (A14)
/A15: J1.8, U1.11 (A15)
/A16: J1.6, U1.10 (A16)
/A17: J1.5, U1.6 (A17)
/A18: J1.3, U1.9 (A18)
/CE: J1.21, U1.30 (*CE)
/D0: J1.28, U1.21 (DQ0)
/D1: J1.30, U1.22 (DQ1)
/D2: J1.32, U1.23 (DQ2)
/D3: J1.31, U1.25 (DQ3)
/D4: J1.29, U1.26 (DQ4)
/D5: J1.27, U1.27 (DQ5)
/D6: J1.25, U1.28 (DQ6)
/D7: J1.23, U1.29 (DQ7)
/OE: J1.17, U1.32 (*OE)
GND: C1.1, J1.2, J1.4, J1.33, J1.34, J1.35, U1.24 (VSS)
unnamed: J1.36, R1.2, U1.7 (*WE)
VCC: C1.2, J1.1, R1.1, U1.8 (VDD)

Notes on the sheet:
In QC1, pin 36 NC, /WE pulled up to VCC In programmer, can be driven low to program
NOTE Reordered pin numbers to match schematic

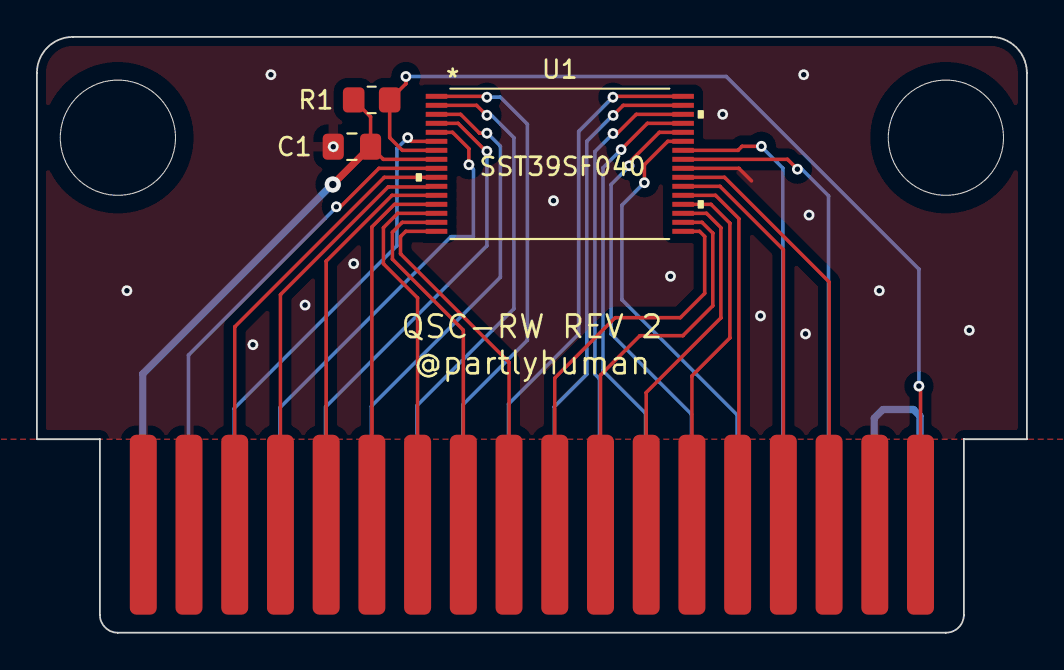
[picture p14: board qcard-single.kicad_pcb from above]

Board: 4 copper layers, 55.0 x 33.1 mm, 6 parts (0 on the bottom side), 32 nets.

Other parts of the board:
H1, H2: MountingHole_6.4mm_M6

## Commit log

2022-12-29 Add dumper PCB v0
    [QCard.kicad_pcb, QCard.kicad_sch]
2023-01-02 Dumper v1
    [QCard.kicad_pcb, QCard.kicad_sch]
2023-01-15 update ignores
    [QCard.kicad_pcb]
2023-01-15 TSOP32 flash cart v0
    [QCard-B_Cu.gbr, QCard-B_Mask.gbr, QCard-B_Paste.gbr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]
2023-01-15 Adds jumper for programming, fixes all DRC errors but loses mounting holes
    [QCard.kicad_pcb, QCard.kicad_sch]
2023-01-15 Restores mounting holes
    [QCard-B_Cu.gbr, QCard-B_Mask.gbr, QCard-B_Paste.gbr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]
2023-01-15 Adds label
    [QCard-B_Cu.gbr, QCard-B_Mask.gbr, QCard-B_Paste.gbr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]
2023-01-15 Nudge mounting holes
    [QCard-B_Cu.gbr, QCard-B_Mask.gbr, QCard-B_Paste.gbr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]
2023-01-15 Remove intermediate directory
    [QCard-B_Cu.gbr, QCard-B_Mask.gbr, QCard-B_Paste.gbr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]
2023-01-16 Better write protect jumper behaviour, using text vars
    [QCard-B_Cu.gbr, QCard-B_Mask.gbr, QCard-B_Paste.gbr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]
2023-01-16 Solve ERC warnings
    [QCard.kicad_sch]
2023-01-19 Pulling WE high for reading per datasheet
    [QCard-B_Cu.gbr, QCard-B_Mask.gbr, QCard-B_Paste.gbr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]
2023-01-19 Center silkscreen
    [QCard-B_Cu.gbr, QCard-B_Mask.gbr, QCard-B_Paste.gbr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]
2023-01-24 Better labeling
    [QCard-B_Cu.gbr, QCard-B_Mask.gbr, QCard-B_Paste.gbr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]
2023-01-24 update date
    [QCard-B_Cu.gbr, QCard-B_Mask.gbr, QCard-B_Paste.gbr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]
2023-01-25 Adds printable case (for standard size Q-card, not minimized one)
    [Q Card Case_Q Card Case v22_Bottom.stl, Q Card Case_Q Card Case v22_Top.stl]
2023-01-25 Adds programmer pcb
    [QCard-B_Cu.gbr, QCard-B_Mask.gbr, QCard-B_Paste.gbr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]
2023-01-26 Extra grounding and better silkscreen positioning on smaller pcb
    [QCard-B_Cu.gbr, QCard-B_Mask.gbr, QCard-B_Paste.gbr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]
2023-02-08 New case design for smaller PCB
    [Q Card Case_Bottom.stl, Q Card Case_Q Card Case v22_Bottom.stl, Q Card Case_Q Card Case v22_Top.stl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]
2023-02-13 Multicart design sketch
    [qcard-multicart.kicad_pcb, qcard-multicart.kicad_sch, qcard-multicart.sch]
2023-02-14 First pass at multicart
    [qcard-multicart.kicad_pcb, qcard-multicart.kicad_sch]
2023-02-14 Maybe usable prototype
    [qcard-multicart-B_Mask.gbr, qcard-multicart-B_Paste.gbr, qcard-multicart-B_Silkscreen.gbr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]
2023-02-14 changing pulldown to pullup
    [qcard-multicart-B_Mask.gbr, qcard-multicart-B_Paste.gbr, qcard-multicart-B_Silkscreen.gbr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]
2023-03-14 I actually don't know what the difference here is
    [QCard-B_Cu.gbr, QCard-B_Mask.gbr, QCard-B_Paste.gbr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]
2023-03-15 Multicart: connect OE/CE instead of always on, solve some DRC violations
    [qcard-multicart-B_Mask.gbr, qcard-multicart-B_Paste.gbr, qcard-multicart-B_Silkscreen.gbr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]
2023-03-15 Multicart: adds missing 3d parts
    [qcard-multicart.kicad_pcb]
2023-03-15 Adding 4mm clearance to switches
    [qcard-multicart-B_Mask.gbr, qcard-multicart-B_Paste.gbr, qcard-multicart-B_Silkscreen.gbr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]
2023-03-15 Adding another 4mm clearance, cutting out dead board
    [qcard-multicart-B_Mask.gbr, qcard-multicart-B_Paste.gbr, qcard-multicart-B_Silkscreen.gbr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]
2023-03-21 Refactor multicart to use SMD resistor array for ease of assembly
    [qcard-multicart.kicad_pcb, qcard-multicart.kicad_sch]
2023-04-02 Adds multicart case 3d print
    [Q Card Multicart Case_Bottom.stl, Q Card Multicart Case_Top.stl]
2023-05-23 Adding Q-Chord schematic because I keep losing it
2023-05-24 Adds board adapting SOP44 maskrom to TSOP48 flash
    [soundbank.kicad_pcb, soundbank.kicad_sch]
2023-05-24 Flip outtie to innie
    [soundbank.kicad_pcb]
2023-05-24 Makes room for neighboring IC
    [soundbank.kicad_pcb, soundbank.kicad_sch]
2023-06-06 Comic sans to match mainboard
    [soundbank.kicad_pcb]
2023-06-06 Redesign in-place
    [soundbank.kicad_pcb]
2023-06-07 Don't leave stuff floating
    [soundbank.kicad_pcb, soundbank.kicad_sch]
2023-06-07 add extra GND
    [soundbank.kicad_pcb, soundbank.kicad_sch]
2023-06-09 Adds some docs, pre-reversed Q616 dump
    [soundbank.kicad_pcb, soundbank.kicad_sch]
2023-09-29 Dual soundbank adapter
    [qchord-dual-soundbank-adapter.kicad_pcb, qchord-dual-soundbank-adapter.kicad_sch]
2023-11-09 pullup instead of pulldown by default
    [qchord-dual-soundbank-adapter.kicad_pcb, qchord-dual-soundbank-adapter.kicad_sch]
2023-12-13 Removes resistor pack, current limits pulled up inputs
    [qcard-multicart-B_Mask.gbr, qcard-multicart-B_Paste.gbr, qcard-multicart-B_Silkscreen.gbr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]
2024-01-13 Move all components to front
    [qcard-multicart.kicad_pcb, qcard-multicart.kicad_sch]
2024-01-13 Production ready files
    [qcard-multicart.kicad_pcb, qcard-multicart.kicad_sch]
2024-04-04 Space out components for easier hand soldering
    [qcard-multicart.kicad_pcb, qcard-multicart.kicad_sch]
2024-04-14 New render
    [qcard-multicart.kicad_pcb]
2024-06-06 Updating case print, moving thread so little bit doesn't snap off
    [Q Card Case_Q Card Multicart Case v15_Bottom.stl, Q Card Case_Q Card Multicart Case v15_Top.stl, Q Card Multicart Case_Bottom.stl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]
2024-06-06 Create project for SAM9713 dev board
    [sam9713-dev.kicad_pcb, sam9713-dev.kicad_sch]
2024-08-28 Remove devboard not really in use
    [sam9713-dev.kicad_pcb, sam9713-dev.kicad_sch]
2024-09-13 Muting B0 and AA events makes only diff the extra pitch bends that were captured and system reset after song end
2024-09-17 Better checking for track ranges
2024-09-22 Revisiting single Qcard, renumber pins to match schematic
    [qcard-single.kicad_pcb, qcard-single.kicad_sch]
2024-09-22 Replace qcard-tsop32
    [QCard-B_Cu.gbr, QCard-B_Mask.gbr, QCard-B_Paste.gbr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]
2024-09-24 Quick and dirty metronome track generation
2024-12-27 Gives 0.5mm extra tolerance to case, wasn't closing well
    [Q Card Case_Q Card Multicart Case v15_Bottom.stl, Q Card Case_Q Card Multicart Case v15_Top.stl, Q Card Case_Q Card Multicart Case v16_Bottom.stl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]
2024-12-29 Minor fitment tweaks to multicart case
    [Q Card Case_Q Card Multicart Case v16_Bottom.stl, Q Card Case_Q Card Multicart Case v16_Top.stl, Q Card Case_Q Card Multicart Case v17_Bottom.stl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]
2025-08-22 Update print with no support holes
    [Q Card Case_Q Card Multicart Case v19_Bottom.stl, Q Card Case_Q Card Multicart Case v19_Top.stl]
2025-12-09 Update multicart case to have tighter fit
    [Q Card Case_Q Card Multicart Case v17_Bottom.3mf, Q Card Case_Q Card Multicart Case v17_Bottom.stl, Q Card Case_Q Card Multicart Case v17_Top.stl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]

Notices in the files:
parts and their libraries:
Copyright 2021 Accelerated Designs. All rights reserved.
